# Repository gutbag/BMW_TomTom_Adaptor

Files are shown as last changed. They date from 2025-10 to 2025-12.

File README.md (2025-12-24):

# BMW Nav Mount To TomTom Adaptor

## Description
These are the design files for an adaptor to allow TomTom sat navs to be mounted on, and powered by, a BMW Nav Mount. The project involves 3D printed components, two PCBs, a 12V/5V converter module and some custom-moulded silicone rubber seals for waterproofing.

## Mechanical Components
The mechanical components are designed using FreeCAD. The model contains the parts for the adaptor and some support components such as the mould and lid for the silicone seals.

### AdaptorBase
Fits to the BMW Nav Mount using the standard locking mechanism. Contains a PCB that connnects to the BMW's 12V supply pins, a magnet to turn on the 12V and two silicone seals to prevent water ingress.

### TomTomMount
Fits into the back of the TomTom. Provides a mechanism for a locator block with locking 'key' so that the TomTom with the mount can be removed from the bike without the rest of the relatively bulky adaptor.

### TomTomLocatorBlock
Fits into the TomTomMount and can be locked to it. Contains a PCB with two pogo pins that supply 5V to the TomTom. A small silicone rubber seal surrounds the pogo pins and should be glued in place.

### InternalSupport
Fits between the TomTomLocatorBlock and the AdaptorBase to keep the TomTom PCB and the BMW PCB in place.

## Electronics
The TomTom and BMW PCBs are designed in KiCad. They are made as a single PCB that needs to be separated before assembly. A 12V/5V buck converter module sits between them.

### BMW PCB
Picks up the 0V and 12V pogo pins from the Nav Mount and provides pads for the wires connecting to the buck converter module. A surface mount LED and current limiting resistor can be fitted to confirm that the 12V is present. This is useful during development but may not be in the final adaptor if the material used for the body is opaque. The PCB holds a silicone seal in place.

It is recommended that the BMW PCB's rear pads are gold plated to improve their lifespan and maintain a low resistance connection. It would also be worth increasing the number of vias on the 0V and 12V tracks.

### TomTom PCB
Requires two pogo pins to be mounted and soldered, plus two wires to the buck converter.

### Buck Converter
Converts the BMW 12V to the 5V required by the TomTom. The module used allows an LED with resistors to be fitted across the output to confirm that the 5V is present.

### Internal Wiring
The wiring between the PCBs and the buck converter needs to be short and follow the openings designed for it, particularly in the InternalSupport component.

## Silicone Seals
The FreeCAD model includes a mould for the three silicone seals. These can be made using two-part silicone resin. A mould lid can be used to control the thickness of the seals, although the innermost part of the BMW PCB seal is open to minimise bubbles.

# Bought-In Parts
TomTom PCB pogo pins: aliexpress. 2mm diameter, 14mm length.
Buck converter: kunkune.co.uk 'Mini Step Down Buck Converter 5-30V, 5V output'

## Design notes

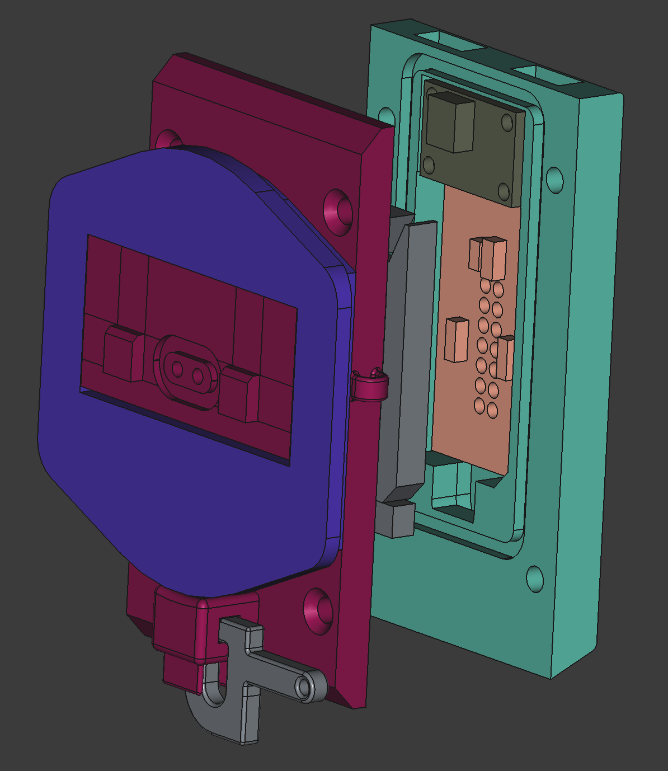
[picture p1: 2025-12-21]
images/FreeCADModel.png

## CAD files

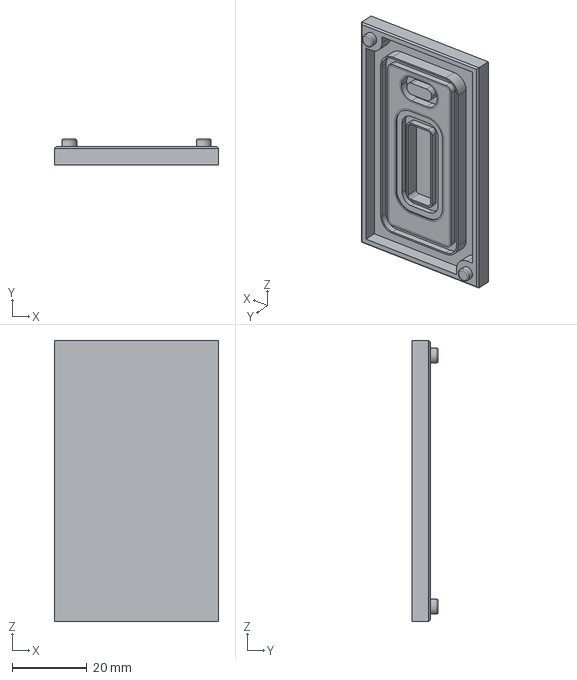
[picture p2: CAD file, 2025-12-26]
BMW_TomTom_Adaptor-SiliconeMoulds.step
44.0 x 7.00 x 75.2 mm

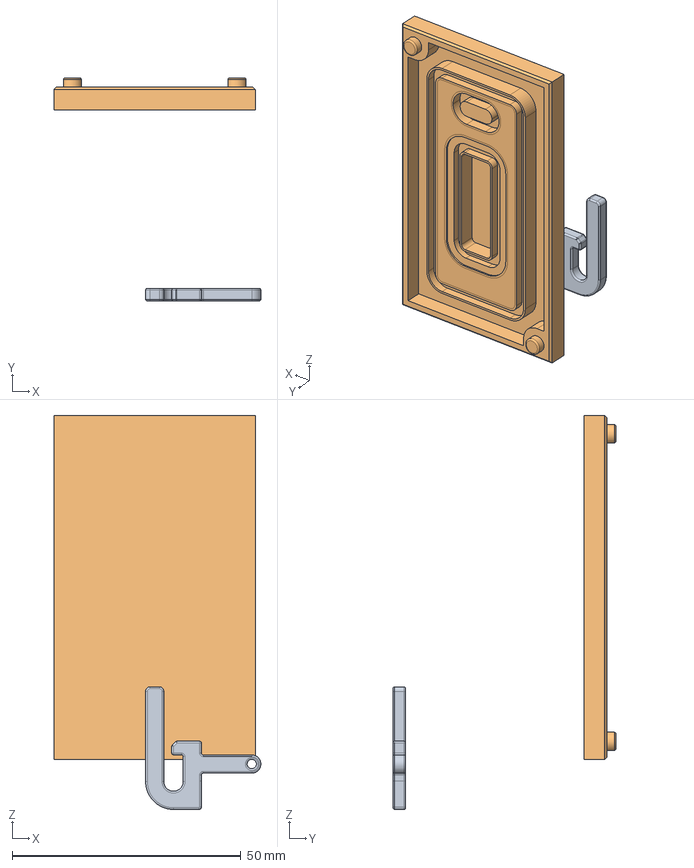
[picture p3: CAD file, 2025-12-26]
BMW_TomTom_Adaptor.FCStd
45.2 x 48.8 x 86.2 mm
VerticalLockKey
SiliconeMoulds

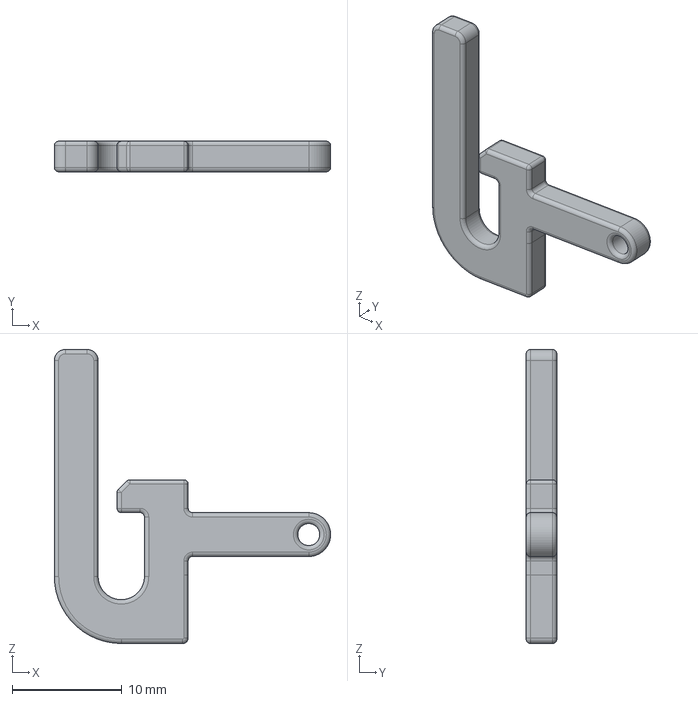
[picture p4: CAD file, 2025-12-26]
BMW_TomTom_Adaptor-VerticalLockKey.step
25.2 x 2.80 x 26.8 mm

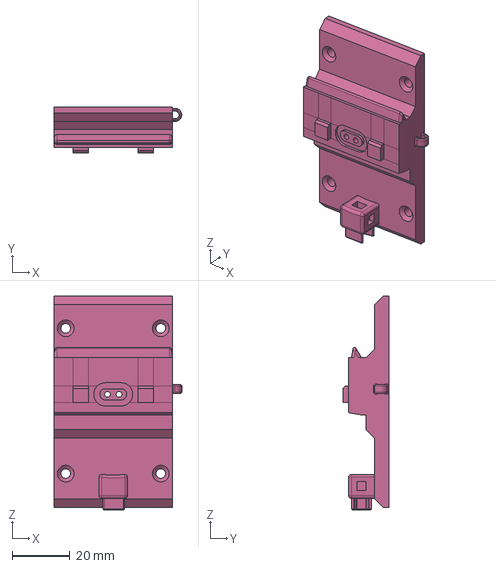
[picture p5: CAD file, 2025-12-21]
BMW_TomTom_Adaptor-TomTomLocatorBlock.step
44.3 x 15.9 x 74.3 mm

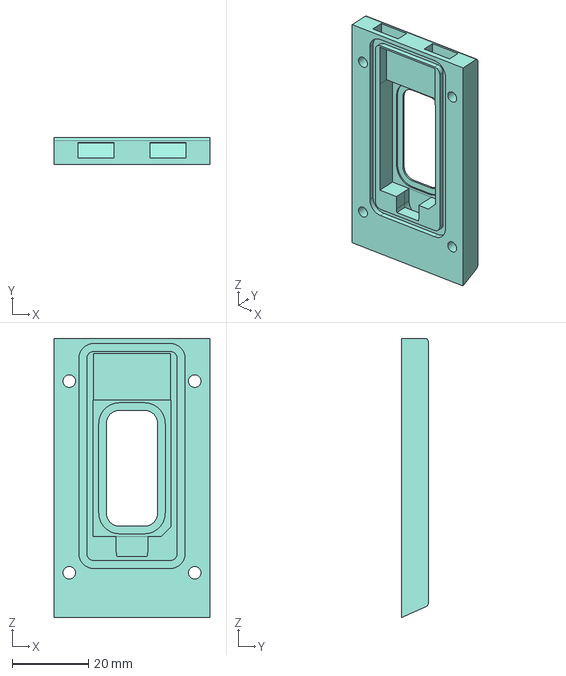
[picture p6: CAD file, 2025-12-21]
BMW_TomTom_Adaptor-AdaptorBase.step
41.0 x 7.00 x 73.4 mm

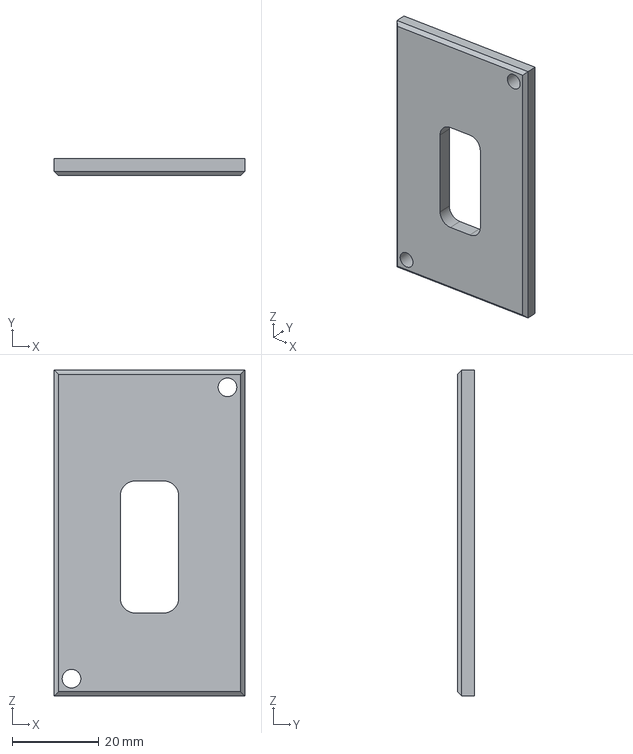
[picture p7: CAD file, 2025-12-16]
BMW_TomTom_Adaptor-SiliconeMouldLid.step
44.0 x 4.00 x 75.2 mm

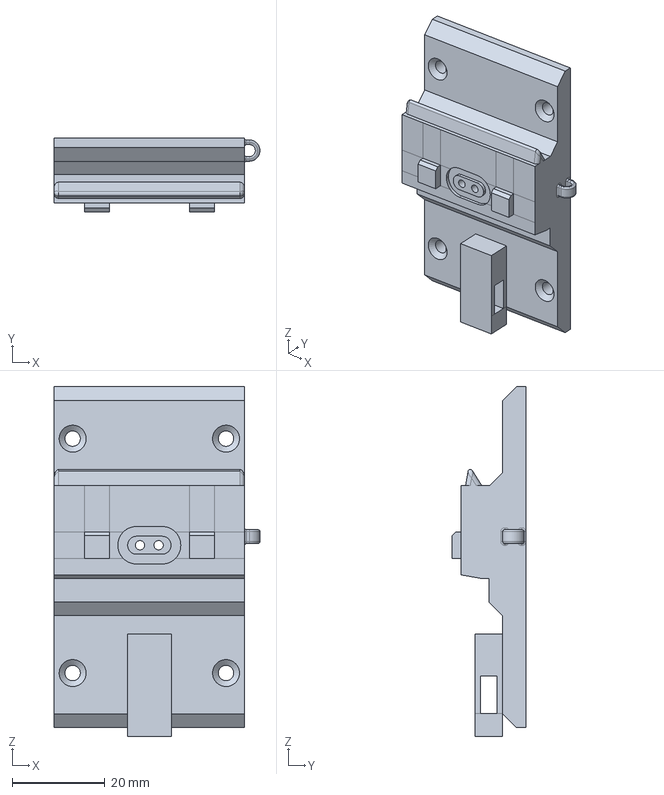
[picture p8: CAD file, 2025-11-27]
BMW_TomTom_Adaptor_backup_1Nov25.FCStd
44.3 x 15.9 x 75.3 mm

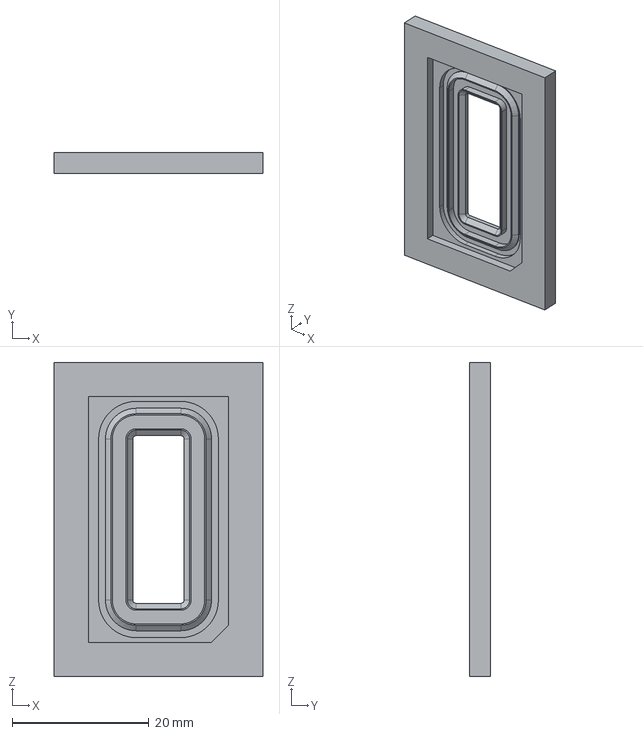
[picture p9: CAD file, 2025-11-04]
BMW_TomTom_Adaptor-BMWSiliconeHelper.step
30.5 x 3.00 x 45.9 mm

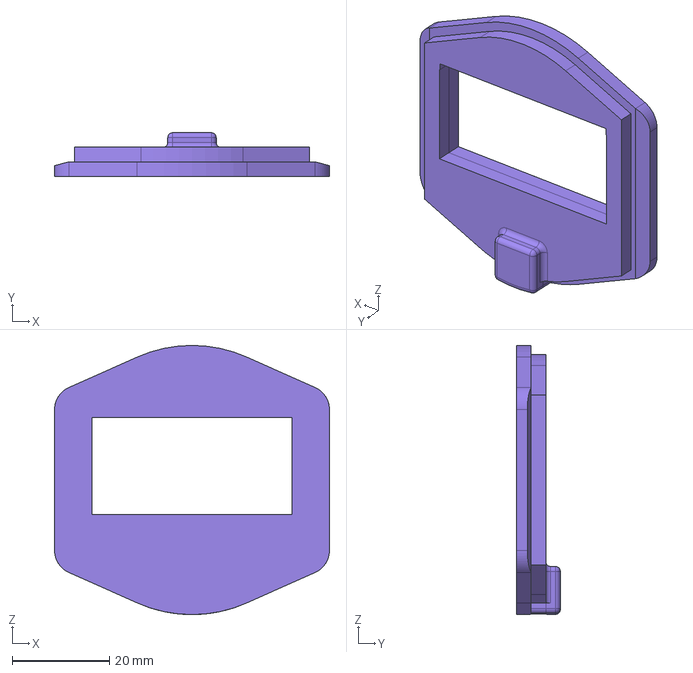
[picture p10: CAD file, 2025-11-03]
BMW_TomTom_Adaptor-TomTomMount.step
56.7 x 9.00 x 55.5 mm

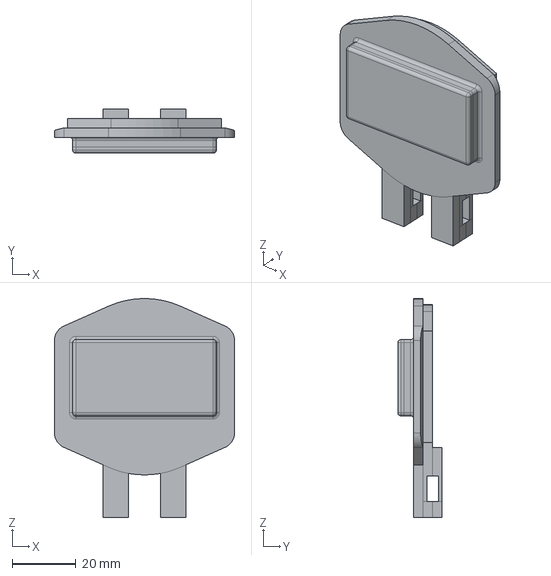
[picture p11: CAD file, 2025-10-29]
BMW_TomTom_Adaptor-TomTomCover.step
56.7 x 14.0 x 68.9 mm

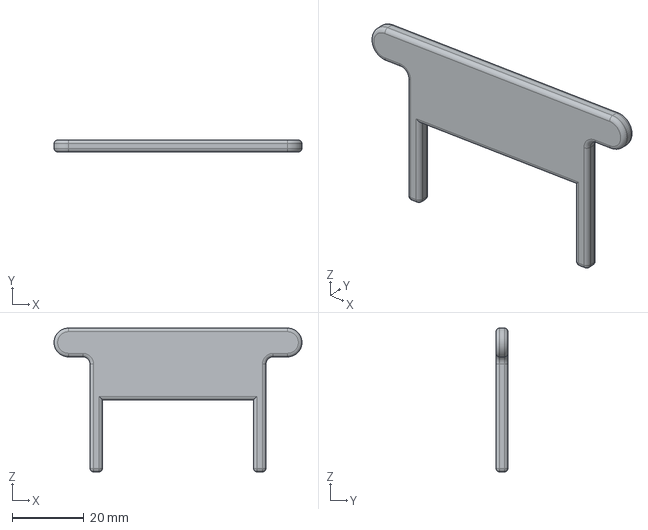
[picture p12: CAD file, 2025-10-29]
BMW_TomTom_Adaptor-TopLockPlate.step
69.0 x 3.30 x 40.0 mm

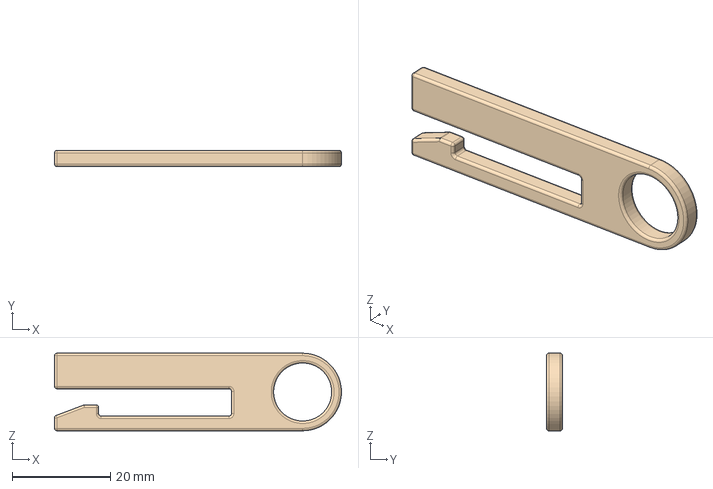
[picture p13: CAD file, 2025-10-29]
BMW_TomTom_Adaptor-BottomLockInsert.step
58.4 x 3.30 x 15.8 mm

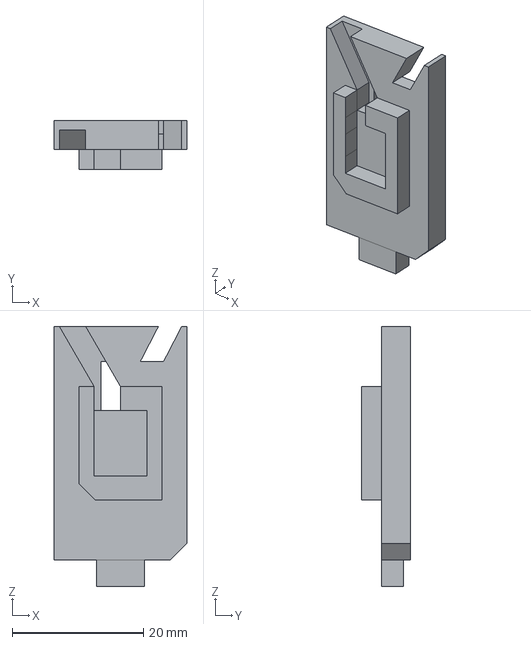
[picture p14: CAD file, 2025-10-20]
BMW_TomTom_Adaptor-InternalSupport.step
20.2 x 7.40 x 39.6 mm

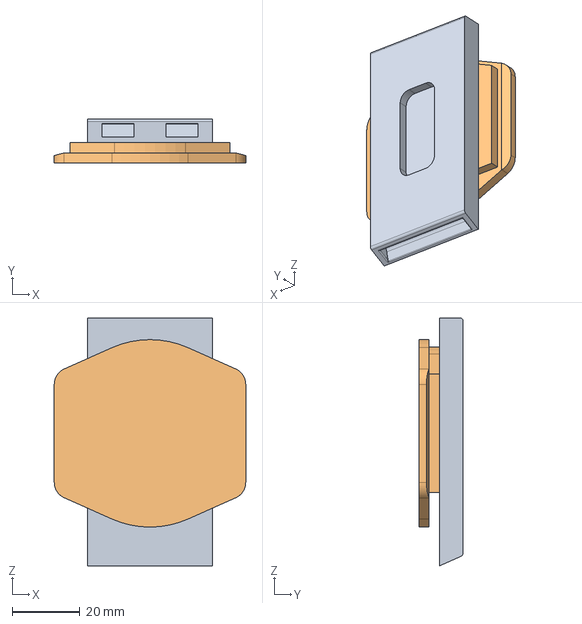
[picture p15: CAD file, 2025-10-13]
BMW_TomTom_Passive_Adaptor.step
56.7 x 13.0 x 73.4 mm
AdaptorBase
TomTomMount

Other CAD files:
BMW_TomTom_Adaptor-TomTomLocatorBlockBuckConverterRecess001.step
BMW_TomTom_Passive_Adaptor.FCStd

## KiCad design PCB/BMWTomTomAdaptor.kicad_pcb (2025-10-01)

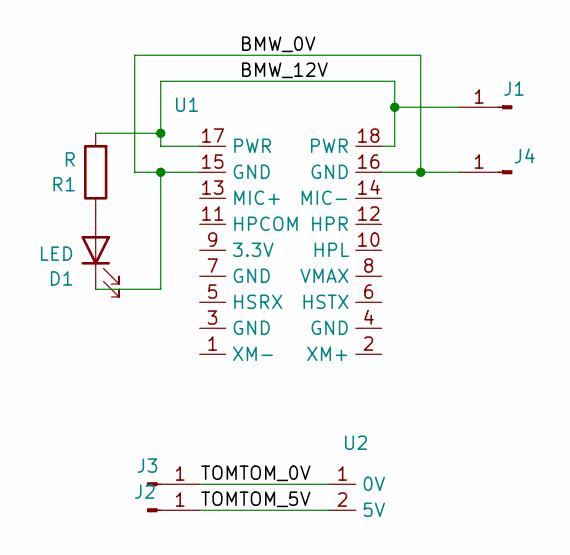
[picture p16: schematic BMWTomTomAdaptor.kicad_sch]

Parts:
D1: LED; LED_1206_3216Metric_Pad1.42x1.75mm_HandSolder
J1, J2, J3, J4: Conn_01x01_Pin; Wire Solder Pad
R1: R; R_0805_2012Metric_Pad1.20x1.40mm_HandSolder
U1: BMWNavConnector
U2: TomTomPogoPins

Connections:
/BMW_0V: D1.1 (K), J4.1, U1.15 (GND), U1.16 (GND)
/BMW_12V: J1.1, R1.2, U1.17 (PWR), U1.18 (PWR)
/TOMTOM_0V: J3.1, U2.1 (0V)
/TOMTOM_5V: J2.1, U2.2 (5V)
unnamed: D1.2 (A), R1.1

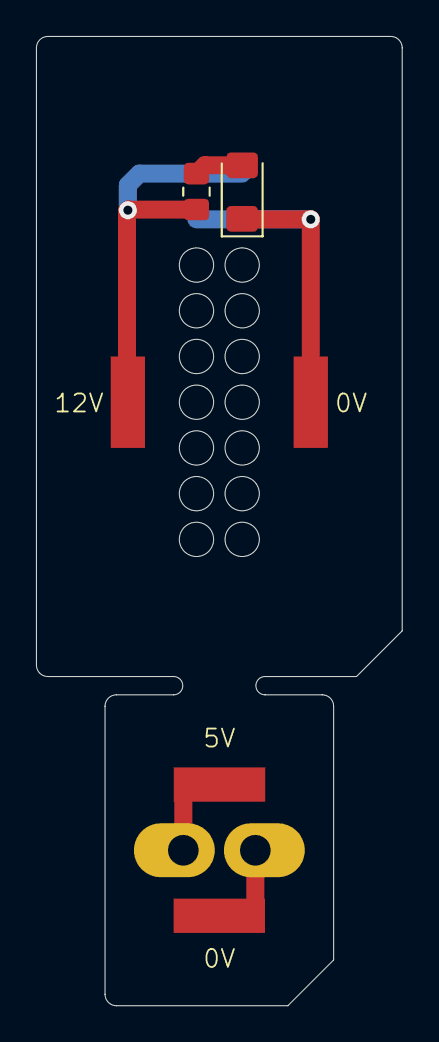
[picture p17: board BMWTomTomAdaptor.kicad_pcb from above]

Board: 2 copper layers, 20.3 x 53.8 mm, 8 parts (1 on the bottom side), 5 nets.

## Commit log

2025-09-18 Slightly updated first version
    [BMW_TomTom_Adaptor.FCStd]
2025-09-18 second print
    [BMW_TomTom_Adaptor.FCStd]
2025-09-18 third print
    [BMW_TomTom_Adaptor.FCStd]
2025-09-18 fourth print
    [BMW_TomTom_Adaptor.FCStd]
2025-09-21 print 5 with separate dummy PCB
    [BMW_TomTom_Adaptor.FCStd]
2025-09-22 changes after print 5
    [BMW_TomTom_Adaptor.FCStd]
2025-09-23 TomTom plate print 1
    [BMW_TomTom_Adaptor.FCStd]
2025-09-23 TomTom plate print 2
    [BMW_TomTom_Adaptor.FCStd]
2025-09-23 TomTom plate print 3
    [BMW_TomTom_Adaptor.FCStd]
2025-09-25 first print of TomTom mount with locator insert
    [BMW_TomTom_Adaptor.FCStd]
2025-09-26 2nd TomTom locator print, 6th adaptor base with magnet
    [BMW_TomTom_Adaptor.FCStd]
2025-09-30 first print of locator with rear plate
    [BMW_TomTom_Adaptor.FCStd]
2025-10-01 First commit of PCB design(s)
    [BMWTomTomAdaptor.kicad_pcb, BMWTomTomAdaptor.kicad_sch]
2025-10-03 Added InternalSupport
    [BMW_TomTom_Adaptor.FCStd]
2025-10-07 Print 7 Oct 25 - added internal support etc.
    [BMW_TomTom_Adaptor-AdaptorBase.step, BMW_TomTom_Adaptor-InternalSupport.step, BMW_TomTom_Adaptor-TomTomLocatorBlock.step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]
2025-10-08 8 Oct 25 print - everything fits but no PCBs yet
    [BMW_TomTom_Adaptor-AdaptorBase.step, BMW_TomTom_Adaptor-InternalSupport.step, BMW_TomTom_Adaptor-TomTomLocatorBlock.step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]
2025-10-13 Added passive adaptor
    [BMW_TomTom_Adaptor.FCStd, BMW_TomTom_Passive_Adaptor.FCStd, BMW_TomTom_Passive_Adaptor.step]
2025-10-20 Printed 20 Oct 2025
    [BMW_TomTom_Adaptor-AdaptorBase.step, BMW_TomTom_Adaptor-InternalSupport.step, BMW_TomTom_Adaptor-TomTomLocatorBlock.step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]
2025-10-20 2nd print 20 Oct 2025
    [BMW_TomTom_Adaptor-TomTomLocatorBlock.step, BMW_TomTom_Adaptor-TomTomMount.step, BMW_TomTom_Adaptor.FCStd]
2025-10-22 Made wider to allow for waterproofing
    [BMW_TomTom_Adaptor.FCStd]
2025-10-22 Added waterproofing slots - provisional
    [BMW_TomTom_Adaptor.FCStd]
2025-10-22 Updated waterproofing for 2mm sq beading
    [BMW_TomTom_Adaptor.FCStd]
2025-10-25 Added TomTomCover
    [BMW_TomTom_Adaptor.FCStd]
2025-10-27 Added simple top lock - not printed
    [BMW_TomTom_Adaptor.FCStd]
2025-10-27 Added bottom lock features and 'key'
    [BMW_TomTom_Adaptor.FCStd]
2025-10-27 Small refinements of lock
    [BMW_TomTom_Adaptor.FCStd]
2025-10-28 Printed 28Oct25
    [BMW_TomTom_Adaptor-AdaptorBase.step, BMW_TomTom_Adaptor-BottomLockInsert.step, BMW_TomTom_Adaptor-TomTomCover2.step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]
2025-10-29 Print 29Oct25 - mostly lock changes
    [BMW_TomTom_Adaptor-BottomLockInsert.step, BMW_TomTom_Adaptor-TomTomCover.step, BMW_TomTom_Adaptor-TomTomCover2.step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]
2025-10-29 Make tether eye stronger
    [BMW_TomTom_Adaptor.FCStd]
2025-11-01 Reduced depth of waterproof channel on TTLocatorBlock
    [BMW_TomTom_Adaptor.FCStd]
2025-11-03 Changed lock to vertical
    [BMW_TomTom_Adaptor-TomTomLocatorBlock.step, BMW_TomTom_Adaptor-TomTomMount.step, BMW_TomTom_Adaptor-VerticalLockKey.step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]
2025-11-04 Added silicone helper and vert lock key
    [BMW_TomTom_Adaptor-BMWSiliconeHelper.step, BMW_TomTom_Adaptor-VerticalLockKey.step, BMW_TomTom_Adaptor.FCStd]
2025-11-27 Added silicone mould
    [BMW_TomTom_Adaptor-SiliconeMoulds.step, BMW_TomTom_Adaptor.FCStd, BMW_TomTom_Adaptor_backup_1Nov25.FCStd]
2025-12-04 Added silicone mould lid and draining recesses
    [BMW_TomTom_Adaptor-SiliconeMouldLid.step, BMW_TomTom_Adaptor-SiliconeMoulds.step, BMW_TomTom_Adaptor.FCStd]
2025-12-09 Small changes after 5 Dec 2025 print
    [BMW_TomTom_Adaptor-SiliconeMoulds.step, BMW_TomTom_Adaptor.FCStd]
2025-12-16 Flange inside adaptor and mould lid opening to try to prevent bubbles
    [BMW_TomTom_Adaptor.FCStd]
2025-12-16 Mould lid with opening
    [BMW_TomTom_Adaptor-SiliconeMouldLid.step]
2025-12-17 Fix BMW seal mould inner edge height
    [BMW_TomTom_Adaptor-SiliconeMoulds.step, BMW_TomTom_Adaptor.FCStd]
2025-12-21 Minor tidying and step export for print 20Dec25
    [BMW_TomTom_Adaptor-AdaptorBase.step, BMW_TomTom_Adaptor-TomTomLocatorBlock.step, BMW_TomTom_Adaptor.FCStd]
2025-12-21 Fixed TTLocatorBlock flip
    [BMW_TomTom_Adaptor-TomTomLocatorBlock.step, BMW_TomTom_Adaptor.FCStd]
2025-12-21 Add doc
    [BMW_TomTom_Adaptor.FCStd]
2025-12-26 Deeper BMW seal and step file for vertical lock
    [BMW_TomTom_Adaptor-SiliconeMoulds.step, BMW_TomTom_Adaptor-VerticalLockKey.step, BMW_TomTom_Adaptor.FCStd]
